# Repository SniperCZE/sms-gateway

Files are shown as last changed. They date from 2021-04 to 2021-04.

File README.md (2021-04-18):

# sms-gateway
Open source / open hardware multiline SMS gateway with HTTP api and RabbitMQ consumer, enclosed in nice 1U custom case.

## Work in progress!

This repo is under development. There is no guarantee that any part of it will not change in the future. Models, schemas and part lists are not final.

## Idea

I would like to have SMS gateway for sending SMS, which:
- receives messages with HTTP API or RabbitMQ queue
- works without active Internet connection
- can be scaled up, can be HA
- looks good
- is not expensive

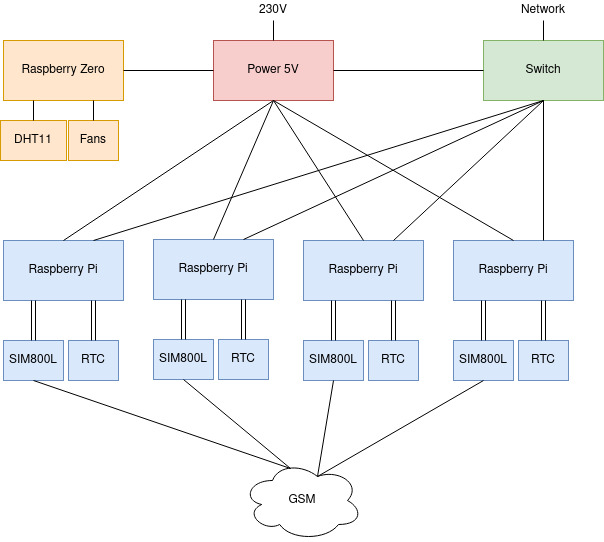
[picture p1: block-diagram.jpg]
SMS gateway block schema


## Electronics

Whole idea is based on raspberry pi minicomputers with SIM800L GSM modules and some custom PCBs. All schematics are KiCAD (https://kicad.org/) projects.

### Power
I'am using one input of 230V AC, converted to 5V DC for every components. There is custom designed PDU board inside of gateway interconnecting all components. Ethernet switch, thermometer and raspberries are powered directly with 5V, GSM module SIM800L must be powered with 4.3V, so I'm using basic diode 1N4007 to drop 5V to 4.3V.

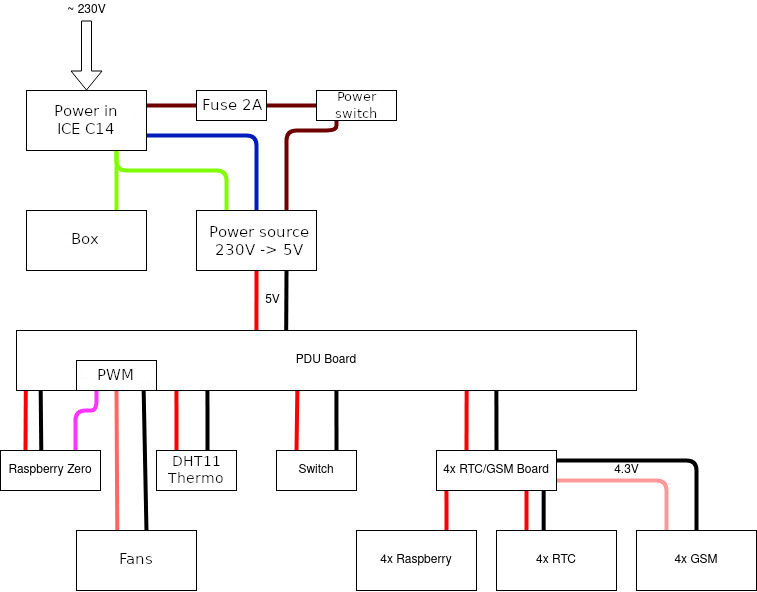
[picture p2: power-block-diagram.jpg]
SMS gateway power distribution


## Mechanics

I will have to build custom 1U rack case for this project. You can find here models ad FreeCAD (https://www.freecadweb.org/) project.

FreeCAD workbenches needed:
- `KiCadStepUp` - integration of KiCAD
- `Fasteners` - screws and nuts
- `Sheet metal` - Support of metal sheet bending
- `Exploded assembly` - Generation of assembly animation

## Software

Every piece of software for my gateway is written in python with some bash scripts and systemd units.

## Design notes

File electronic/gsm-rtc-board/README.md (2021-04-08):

# GSM + RTC board

This board handles RTC and GSM modules, connects them to Raspberry and provide power for modules and Raspberry

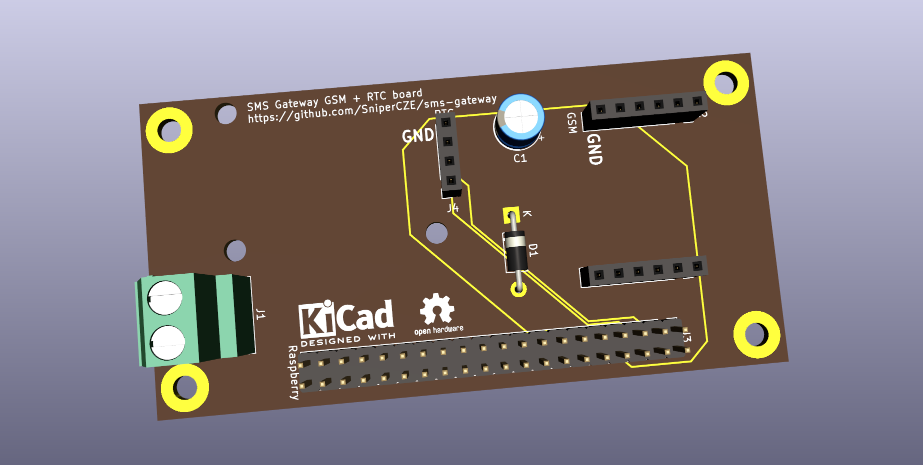
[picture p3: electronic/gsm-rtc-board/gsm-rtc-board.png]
PDU board


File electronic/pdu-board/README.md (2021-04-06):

# PDU board

This board is used for distribution of +5V and GND across all parts of gateway.

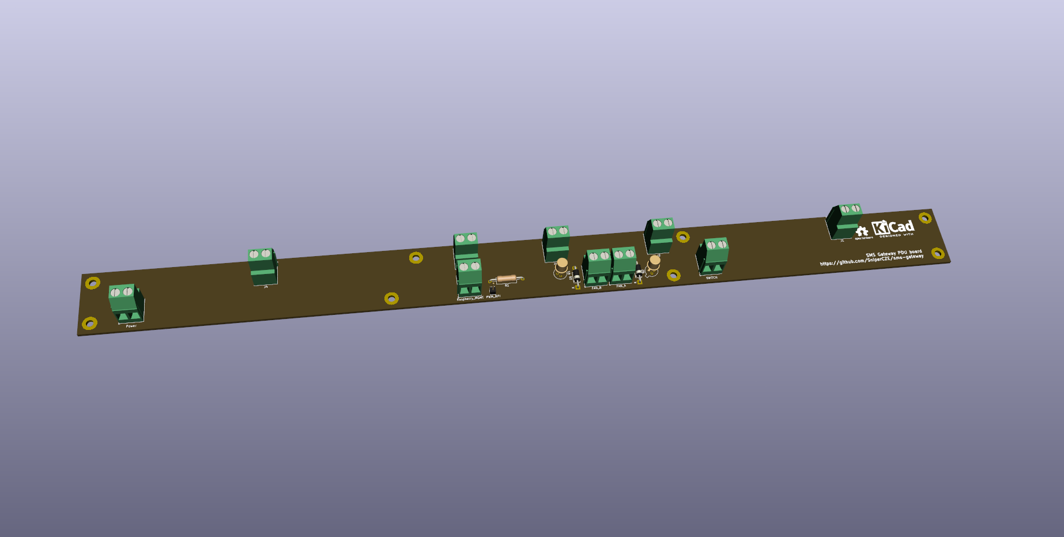
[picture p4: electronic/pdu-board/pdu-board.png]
PDU board


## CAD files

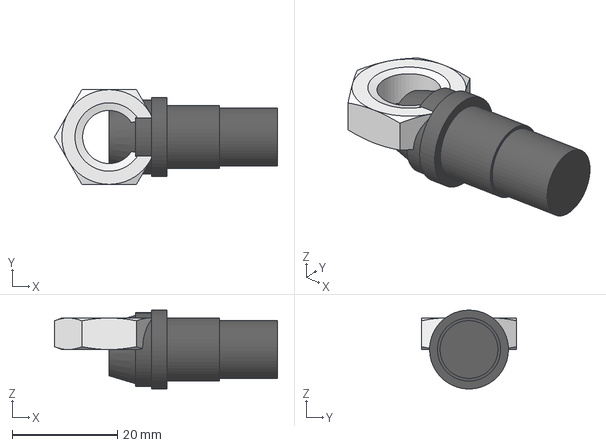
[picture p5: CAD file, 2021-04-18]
mechanic/rack-mount-case.FCStd
42.4 x 18.0 x 15.0 mm
pojistka
M12-Nut

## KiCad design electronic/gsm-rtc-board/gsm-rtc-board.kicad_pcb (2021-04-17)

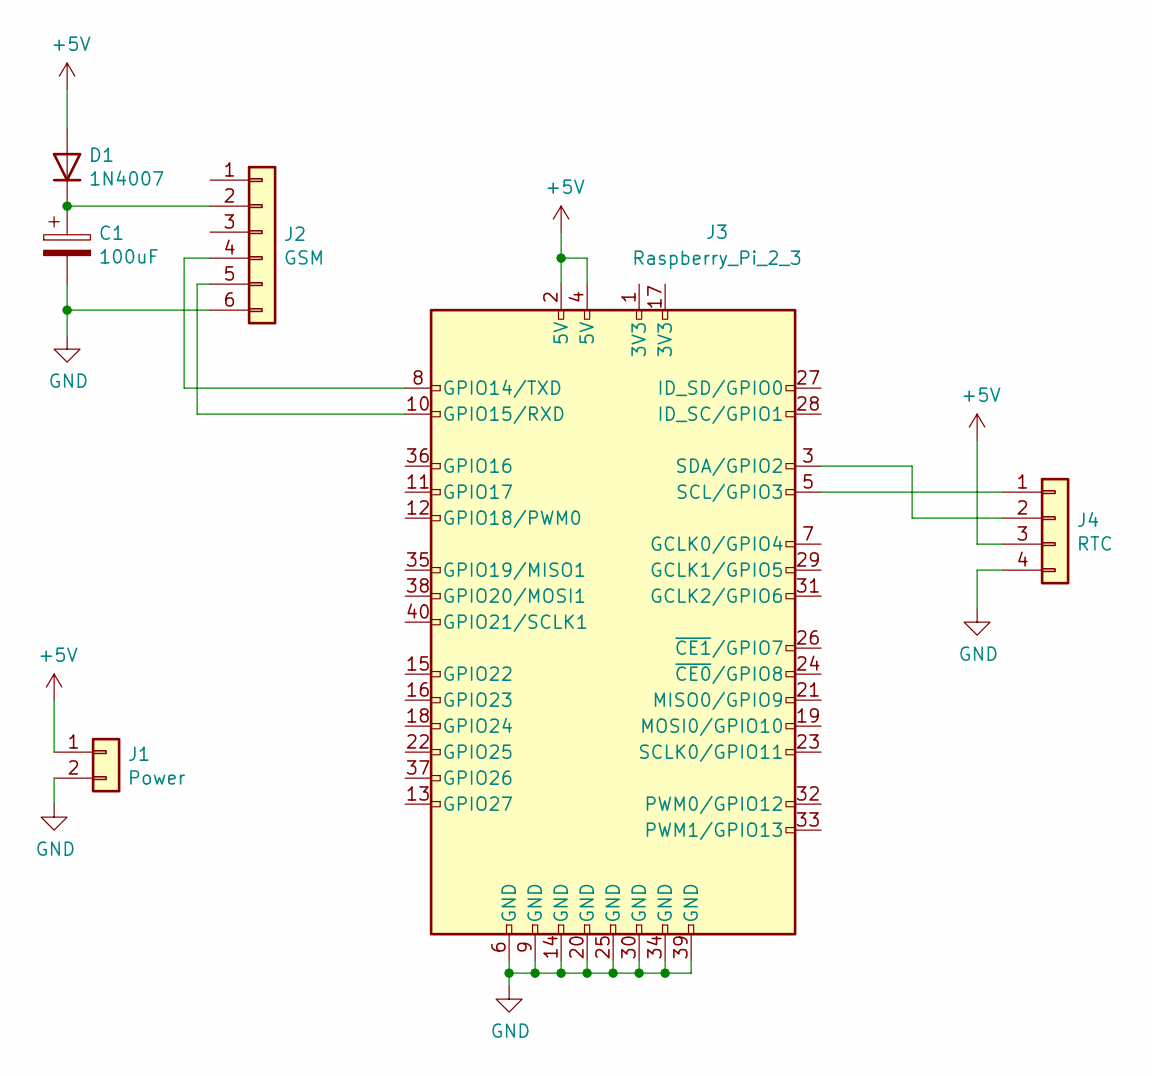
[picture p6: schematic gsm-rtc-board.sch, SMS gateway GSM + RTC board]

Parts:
C1: 100uF; CP_Radial_D6.3mm_P2.50mm
D1: 1N4007; D_DO-41_SOD81_P10.16mm_Horizontal
J1: Power; TerminalBlock_Phoenix_MKDS-3-2-5.08_1x02_P5.08mm_Horizontal
J2: GSM; PinSocket_1x06_P2.54mm_Vertical
J3: Raspberry_Pi_2_3; PinHeader_2x20_P2.54mm_Vertical
J4: RTC; PinSocket_1x04_P2.54mm_Vertical

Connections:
+5V: D1.2 (A), J1.1, J3.2 (5V), J3.4 (5V), J4.3
GND: C1.2, J1.2, J2.6, J3.6 (GND), J3.9 (GND), J3.14 (GND), J3.20 (GND), J3.25 (GND), J3.30 (GND), J3.34 (GND), J3.39 (GND), J4.4
unnamed: C1.1, D1.1 (K), J2.2
unnamed: J2.4, J3.8 (GPIO14/TXD)
unnamed: J2.5, J3.10 (GPIO15/RXD)
unnamed: J3.3 (SDA/GPIO2), J4.2
unnamed: J3.5 (SCL/GPIO3), J4.1

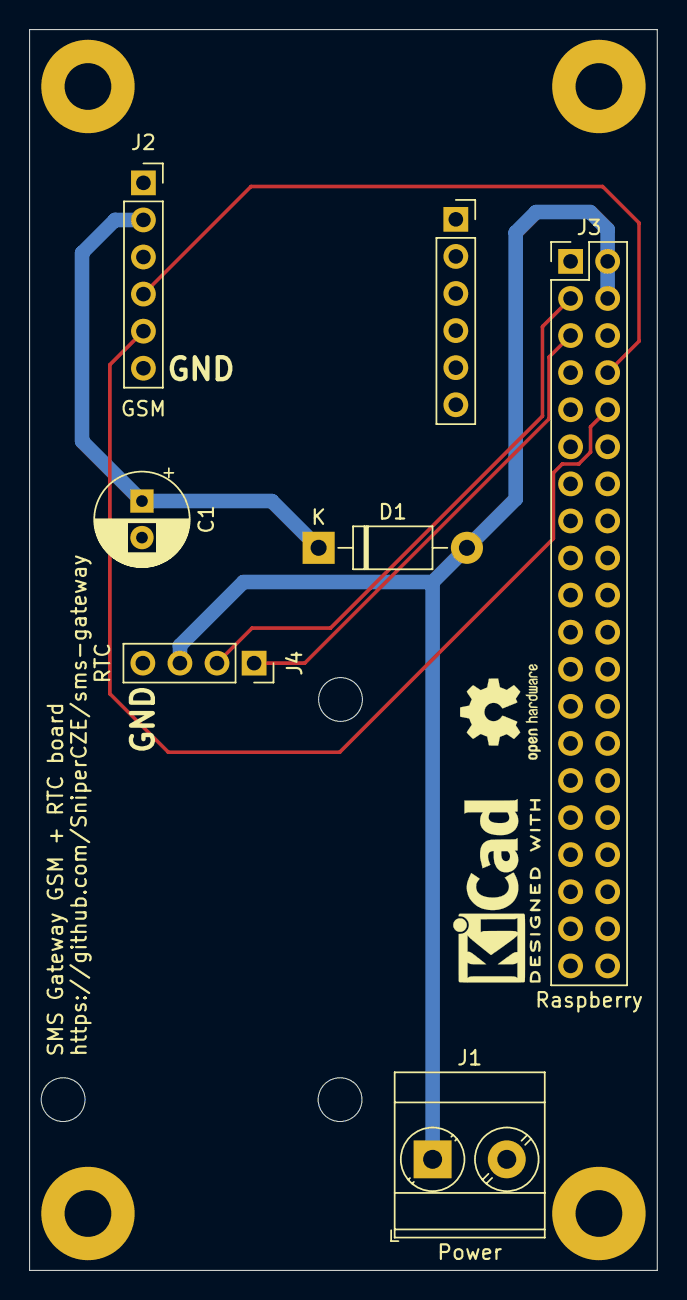
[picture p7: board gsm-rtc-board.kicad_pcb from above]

Board: 2 copper layers, 43.0 x 85.0 mm, 6 parts (0 on the bottom side), 7 nets.

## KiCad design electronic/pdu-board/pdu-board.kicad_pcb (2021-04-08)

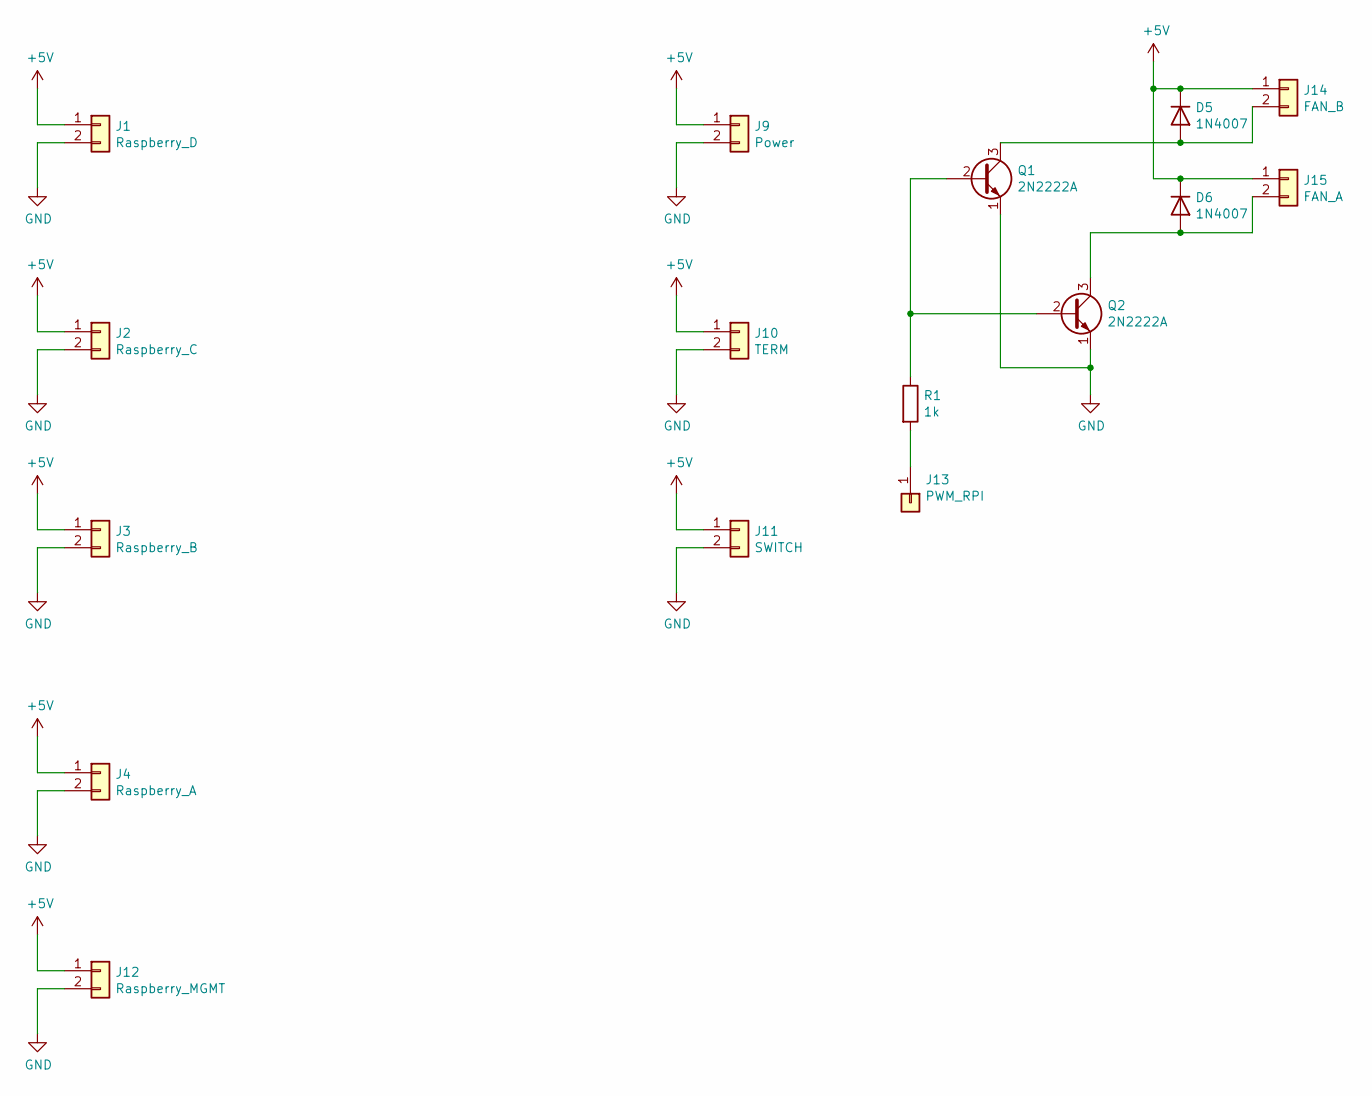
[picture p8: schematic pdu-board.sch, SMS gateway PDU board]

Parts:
D5, D6: 1N4007; D_DO-41_SOD81_P10.16mm_Horizontal
J1: Raspberry_D; TerminalBlock_Phoenix_MKDS-3-2-5.08_1x02_P5.08mm_Horizontal
J2: Raspberry_C; TerminalBlock_Phoenix_MKDS-3-2-5.08_1x02_P5.08mm_Horizontal
J3: Raspberry_B; TerminalBlock_Phoenix_MKDS-3-2-5.08_1x02_P5.08mm_Horizontal
J4: Raspberry_A; TerminalBlock_Phoenix_MKDS-3-2-5.08_1x02_P5.08mm_Horizontal
J9: Power; TerminalBlock_Phoenix_MKDS-3-2-5.08_1x02_P5.08mm_Horizontal
J10: TERM; TerminalBlock_Phoenix_MKDS-3-2-5.08_1x02_P5.08mm_Horizontal
J11: SWITCH; TerminalBlock_Phoenix_MKDS-3-2-5.08_1x02_P5.08mm_Horizontal
J12: Raspberry_MGMT; TerminalBlock_Phoenix_MKDS-3-2-5.08_1x02_P5.08mm_Horizontal
J13: PWM_RPI; PinHeader_1x01_P2.54mm_Vertical
J14: FAN_B; TerminalBlock_Phoenix_MKDS-3-2-5.08_1x02_P5.08mm_Horizontal
J15: FAN_A; TerminalBlock_Phoenix_MKDS-3-2-5.08_1x02_P5.08mm_Horizontal
Q1, Q2: 2N2222A; TO-18-3
R1: 1k; R_Axial_DIN0309_L9.0mm_D3.2mm_P15.24mm_Horizontal

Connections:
+5V: D5.1 (K), D6.1 (K), J1.1, J2.1, J3.1, J4.1, J9.1, J10.1, J11.1, J12.1, J14.1, J15.1
GND: J1.2, J2.2, J3.2, J4.2, J9.2, J10.2, J11.2, J12.2, Q1.1 (E), Q2.1 (E)
unnamed: D5.2 (A), J14.2, Q1.3 (C)
unnamed: D6.2 (A), J15.2, Q2.3 (C)
unnamed: J13.1, R1.2
unnamed: Q1.2 (B), Q2.2 (B), R1.1

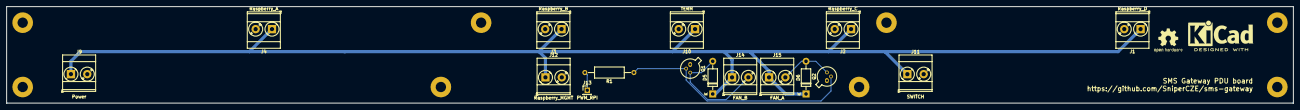
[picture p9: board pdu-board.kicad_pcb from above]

Board: 2 copper layers, 400.0 x 30.0 mm, 16 parts (0 on the bottom side), 6 nets.

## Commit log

2021-03-30 PDU board schematic
    [pdu-board.kicad_pcb, pdu-board.sch]
2021-03-31 PDU board schematic project
    [pdu-board-B_Cu.gbl, pdu-board-B_Mask.gbs, pdu-board-B_SilkS.gbo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]
2021-04-06 Readme + repo structure
    [pdu-board-B_Cu.gbl, pdu-board-B_Mask.gbs, pdu-board-B_SilkS.gbo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]
2021-04-08 RTC + GSM board
    [gsm-rtc-board-B_Cu.gbr, gsm-rtc-board-B_Mask.gbr, gsm-rtc-board-B_SilkS.gbr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]
2021-04-08 rtc mounting holes
    [gsm-rtc-board-B_Cu.gbl, gsm-rtc-board-B_Mask.gbs, gsm-rtc-board-B_SilkS.gbo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]
2021-04-08 Rack case WIP
    [rack-mount-case.FCStd]
2021-04-17 GSM sockets slightly off
    [gsm-rtc-board-B_Cu.gbl, gsm-rtc-board-B_Mask.gbs, gsm-rtc-board-B_SilkS.gbo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]
2021-04-18 Block diagram for power
    [rack-mount-case.FCStd]
